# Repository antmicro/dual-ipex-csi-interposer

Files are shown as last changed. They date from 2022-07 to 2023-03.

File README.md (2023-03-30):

# Dual I-PEX CSI Interposer

Copyright (c) 2022-2023 [Antmicro](https://www.antmicro.com)



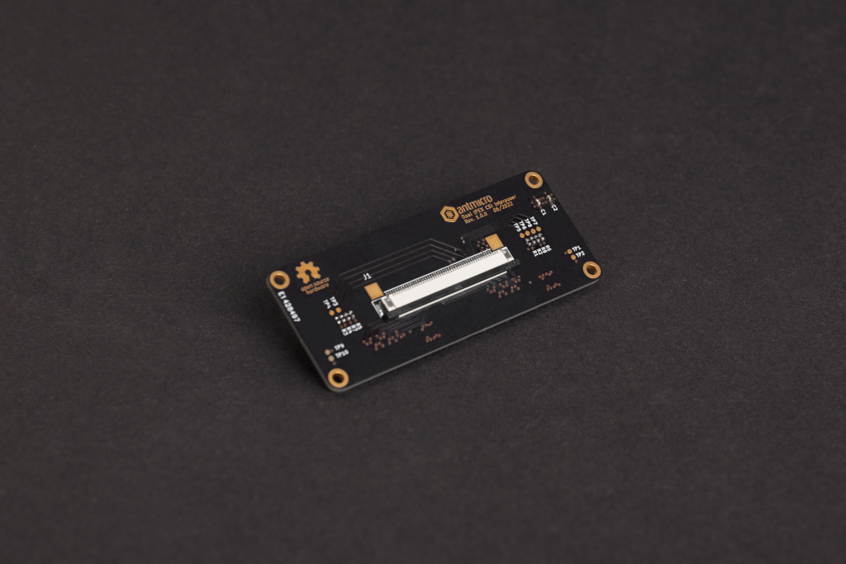
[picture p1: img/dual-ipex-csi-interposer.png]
Dual IPEX CSI Interposer Visualization


## Overview

This repository contains open hardware design files for the Dual I-PEX micro-coaxial CSI Interposer.
The board serves as a 2-to-1 CSI-2 camera cable adapter.

It features two 30-pin I-PEX camera connectors with a 4-lane MIPI CSI-2 interface, I2C and power supply as well as a single upstream connector - 50-pin FFC, compatible with video processing boards created by Antmicro such as:

* [TX2 Deep Learning Platform](https://github.com/antmicro/jetson-tx2-deep-learning-platform) supporting NVIDIA Jetson TX2 
* [AGX CSI Adapter](https://github.com/antmicro/jetson-nano-baseboard) supporting NVIDIA Jetson Xavier AGX and NVIDIA Jetson Orin AGX
* [Jetson Nano Baseboard](https://github.com/antmicro/jetson-nano-baseboard) supporting NVIDIA Jetson Nano, Jetson Xavier NX, Jetson TX2 NX
* [AMD-Xilinx Kria K26 Devboard](https://github.com/antmicro/kria-k26-devboard)
* [Antmicro's Snapdragon 625 baseboard](https://github.com/antmicro/snapdragon-625-baseboard)
* [Antmicro's Snapdragon 845 baseboard](https://github.com/antmicro/snapdragon-845-baseboard)

## Repository structure

The main repository directory contains KiCad PCB project files, a [LICENSE](LICENSE), and a README.
The remaining files are stored in the following directories:

* `lib` - contains the component libraries,
* `doc` - contains the adapter [schematics](doc/dual-ipex-csi-interposer.pdf),
* `img` - contains the board visualization.

## Key features

* 50-pin dual MIPI CSI-2 FFC connector (host side),
* twin 30-wire I-PEX micro coax CSI-2 connectors (camera side) (interface compatible with the [Framos CSI Adapter](https://github.com/antmicro/framos-csi-adapter)),
* 4-lane MIPI CSI-2 per camera.

## License

This project is published under the [Apache-2.0](LICENSE) license.

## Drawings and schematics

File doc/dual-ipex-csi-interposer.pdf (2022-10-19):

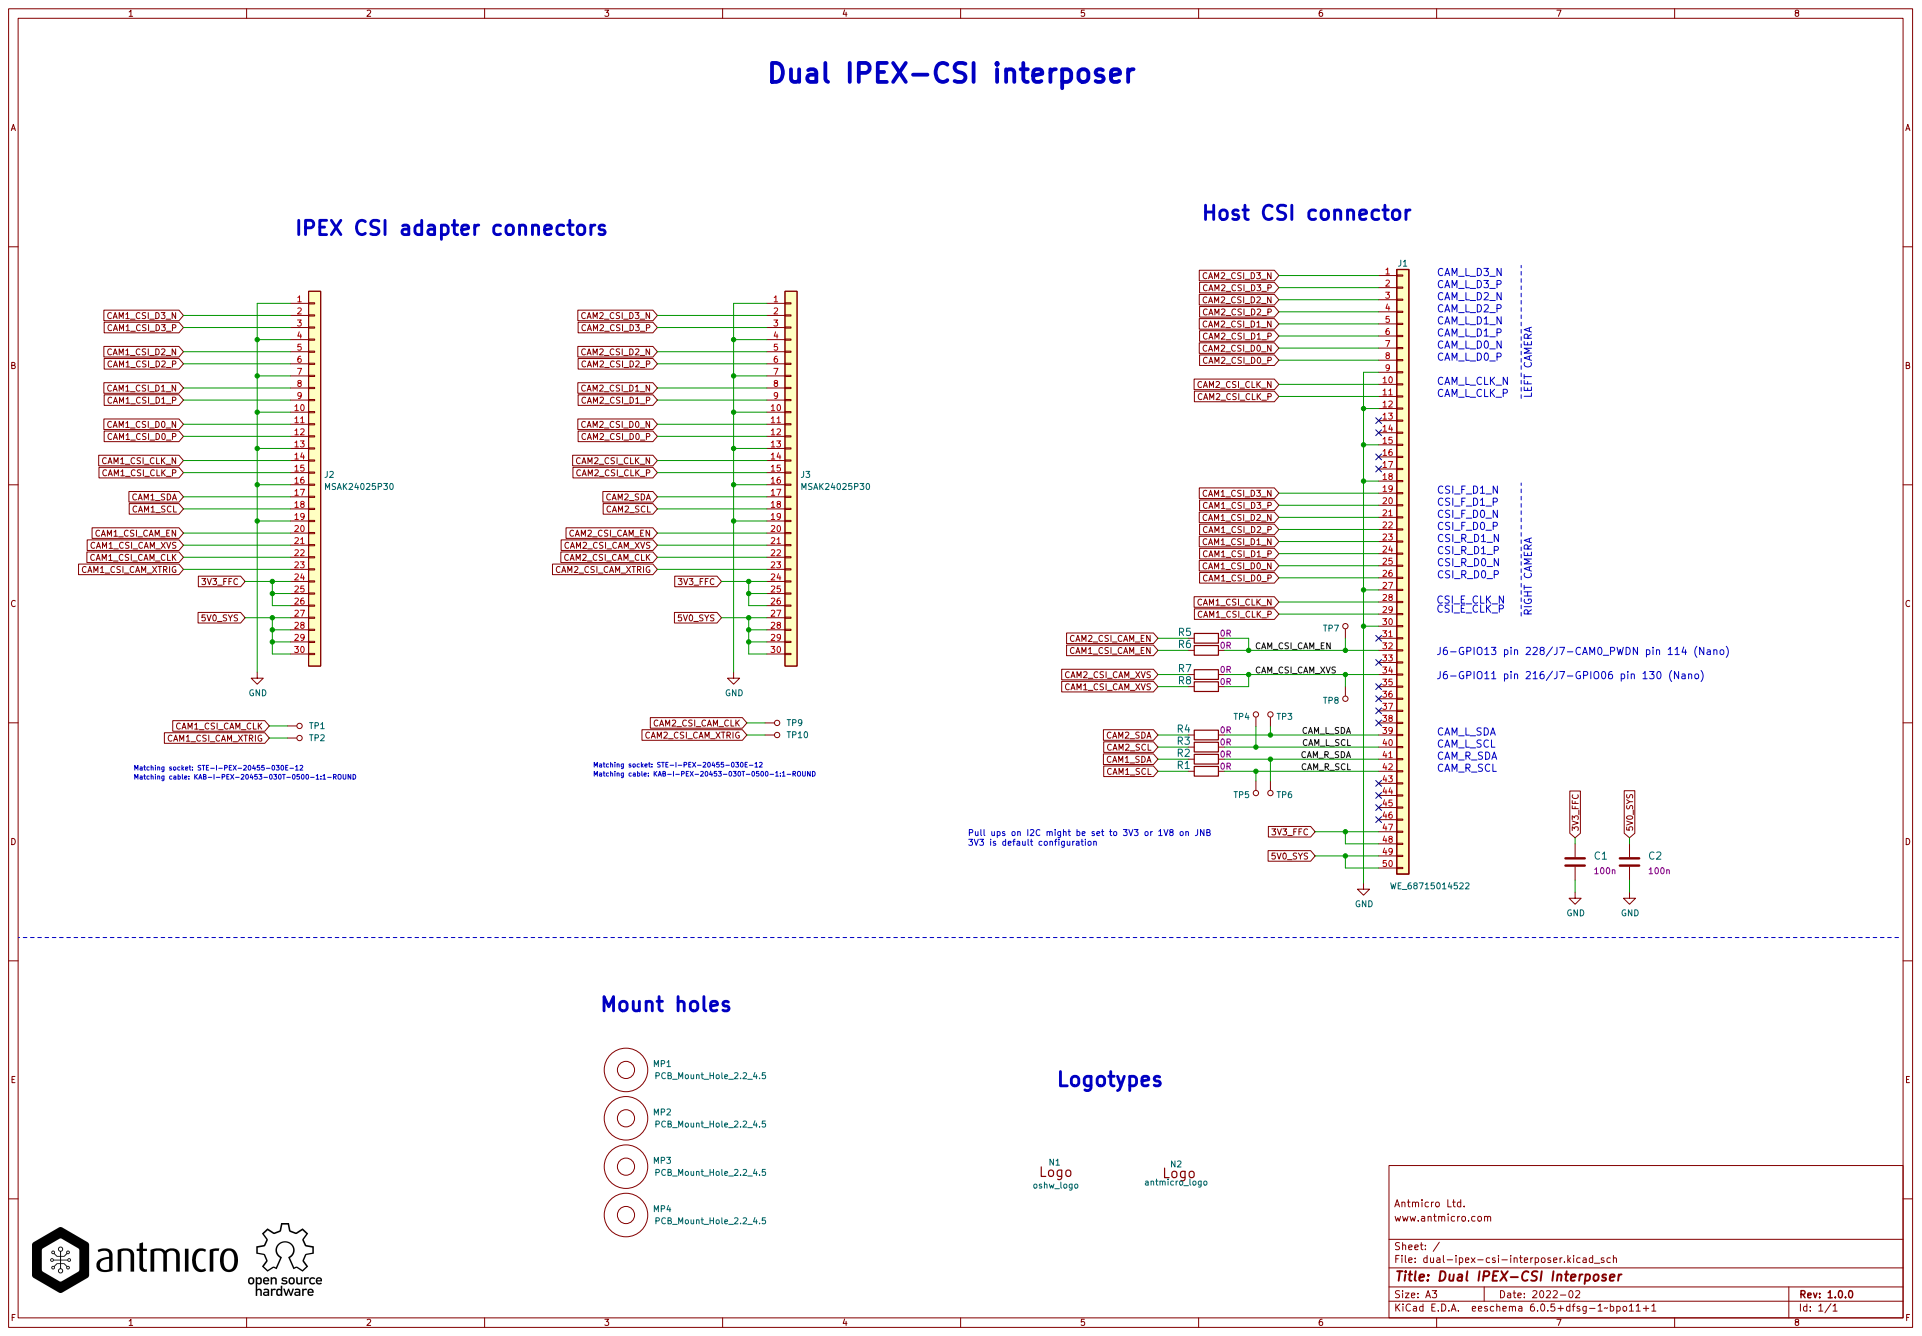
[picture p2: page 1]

IPEX CSI adapter connectors

Pull ups on I2C might be set to 3V3 or 1V8 on JNB
3V3 is default configuration

File: dual-ipex-csi-interposer.kicad_sch Sheet: / www.antmicro.com

Id: 1/1 Title: Dual IPEX-CSI Interposer

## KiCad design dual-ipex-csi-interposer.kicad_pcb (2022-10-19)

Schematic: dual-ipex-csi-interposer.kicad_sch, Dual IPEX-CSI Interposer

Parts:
C1, C2: C_100n_0402; 0402-cap; MPN GRM155R61H104KE14D
J1: WE_68715014522; MPN 68715014522
J2, J3: MSAK24025P30; MPN MSAK24025P30
MP1, MP2, MP3, MP4: PCB_Mount_Hole_2.2_4.5; mounting-hole-2.2mm
N1: oshw_logo; oshw-logo
N2: antmicro_logo; antmicro-logo_scaled_12mm
R1, R2, R3, R4, R5, R6, R7, R8: R_0R_0402; 0402-res; MPN ERJ2GE0R00X
TP1, TP2, TP3, TP4, TP5, TP6, TP7, TP8, TP9, TP10: TP_SMD1MM; Testpoint_smd_1mm

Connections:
3V3_FFC: C1.1, J1.47, J1.48, J2.24, J2.25, J2.26, J3.24, J3.25, J3.26
5V0_SYS: C2.1, J1.49, J1.50, J2.27, J2.28, J2.29, J2.30, J3.27, J3.28, J3.29, J3.30
/CAM_CSI_CAM_EN: J1.32, R5.2, R6.2, TP7.1
/CAM_CSI_CAM_XVS: J1.34, R7.2, R8.2, TP8.1
/CAM_L_SCL: J1.40, R3.2, TP4.1
/CAM_L_SDA: J1.39, R4.2, TP3.1
/CAM_R_SCL: J1.42, R1.2, TP5.1
/CAM_R_SDA: J1.41, R2.2, TP6.1
CAM1_CSI_CAM_CLK: J2.22, TP1.1
CAM1_CSI_CAM_EN: J2.20, R6.1
CAM1_CSI_CAM_XTRIG: J2.23, TP2.1
CAM1_CSI_CAM_XVS: J2.21, R8.1
CAM1_CSI_CLK_N: J1.28, J2.14
CAM1_CSI_CLK_P: J1.29, J2.15
CAM1_CSI_D0_N: J1.25, J2.11
CAM1_CSI_D0_P: J1.26, J2.12
CAM1_CSI_D1_N: J1.23, J2.8
CAM1_CSI_D1_P: J1.24, J2.9
CAM1_CSI_D2_N: J1.21, J2.5
CAM1_CSI_D2_P: J1.22, J2.6
CAM1_CSI_D3_N: J1.19, J2.2
CAM1_CSI_D3_P: J1.20, J2.3
CAM1_SCL: J2.18, R1.1
CAM1_SDA: J2.17, R2.1
CAM2_CSI_CAM_CLK: J3.22, TP9.1
CAM2_CSI_CAM_EN: J3.20, R5.1
CAM2_CSI_CAM_XTRIG: J3.23, TP10.1
CAM2_CSI_CAM_XVS: J3.21, R7.1
CAM2_CSI_CLK_N: J1.10, J3.14
CAM2_CSI_CLK_P: J1.11, J3.15
CAM2_CSI_D0_N: J1.7, J3.11
CAM2_CSI_D0_P: J1.8, J3.12
CAM2_CSI_D1_N: J1.5, J3.8
CAM2_CSI_D1_P: J1.6, J3.9
CAM2_CSI_D2_N: J1.3, J3.5
CAM2_CSI_D2_P: J1.4, J3.6
CAM2_CSI_D3_N: J1.1, J3.2
CAM2_CSI_D3_P: J1.2, J3.3
CAM2_SCL: J3.18, R3.1
CAM2_SDA: J3.17, R4.1
GND: C1.2, C2.2, J1.9, J1.12, J1.15, J1.18, J1.27, J1.30, J2.1, J2.4, J2.7, J2.10, J2.13, J2.16, J2.19, J3.1, J3.4, J3.7, J3.10, J3.13, J3.16, J3.19

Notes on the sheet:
CAM_L_D1_P
CAM_L_SDA
CSI_E_CLK_N
CSI_E_CLK_P
CAM_L_D2_P
CAM_R_SCL
Matching cable: KAB-I-PEX-20453-030T-0500-1:1-ROUND
Pull ups on I2C might be set to 3V3 or 1V8 on JNB 3V3 is default configuration
CAM_L_D0_N
CSI_F_D0_P
Text
CSI_R_D0_P
CAM_L_D0_P
CAM_L_D1_N
Dual IPEX-CSI interposer
CSI_R_D1_P
CAM_L_CLK_P
CSI_R_D1_N
J6-GPIO13 pin 228/J7-CAM0_PWDN pin 114 (Nano)
Mount holes
Matching socket: STE-I-PEX-20455-030E-12
CAM_L_D3_P
CAM_R_SDA
LEFT CAMERA
CAM_L_CLK_N
CSI_F_D1_P
J6-GPIO11 pin 216/J7-GPIO06 pin 130 (Nano)
IPEX CSI adapter connectors
RIGHT CAMERA
CSI_R_D0_N
Logotypes
CSI_F_D0_N
CAM_L_D3_N
Host CSI connector
CAM_L_D2_N
CSI_F_D1_N
CAM_L_SCL

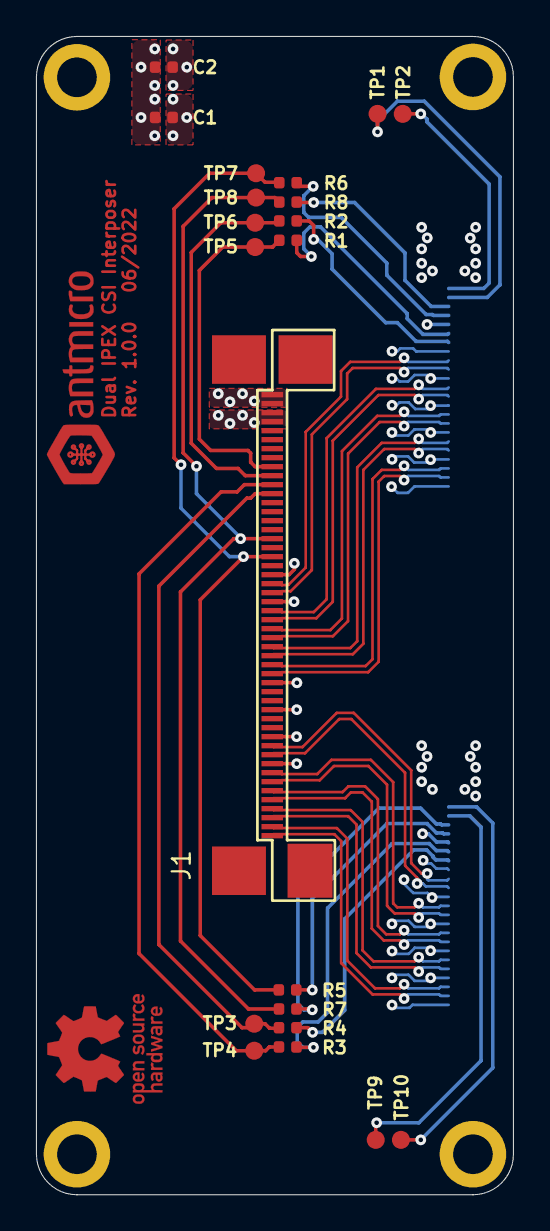
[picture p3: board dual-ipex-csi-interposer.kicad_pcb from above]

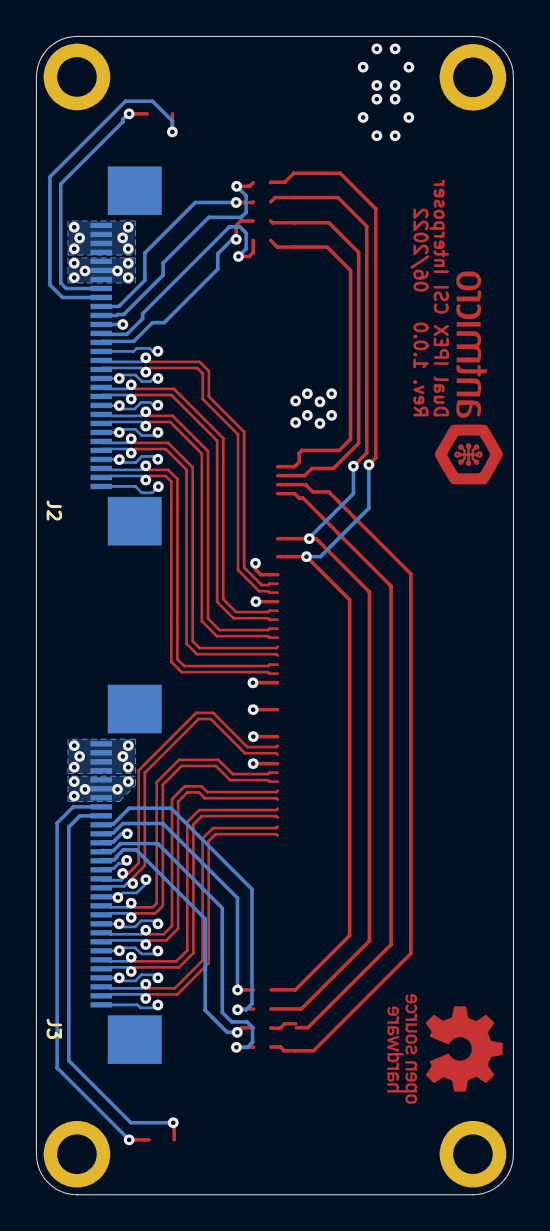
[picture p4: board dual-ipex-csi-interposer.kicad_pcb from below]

Board: 4 copper layers, 26.5 x 64.3 mm, 29 parts (2 on the bottom side), 41 nets.

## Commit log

2022-07-28 Initial commit. Add single IPEX
    Fix library issue
    [antmicro-dual-ipex-csi-interposer.kicad_pcb, antmicro-dual-ipex-csi-interposer.kicad_sch, antmicro-dual-ipex-csi-interposer.sch]
2022-07-28 Add second connector and assigned signals
    Remove Kicad5 CI
    [antmicro-dual-ipex-csi-interposer.kicad_pcb, antmicro-dual-ipex-csi-interposer.kicad_sch, antmicro-dual-ipex-csi-interposer.sch]
2022-07-28 Complete schematic. Proceed PCB layout
    [antmicro-dual-ipex-csi-interposer.kicad_pcb, antmicro-dual-ipex-csi-interposer.kicad_sch]
2022-07-28 Route low speed, optimize polygons, match lane length
    [antmicro-dual-ipex-csi-interposer.kicad_pcb, antmicro-dual-ipex-csi-interposer.kicad_sch]
2022-07-28 Add decoupling, move all TP to the top
    Cosmetic changes
    Capital letter fix
    [antmicro-dual-ipex-csi-interposer.kicad_pcb, antmicro-dual-ipex-csi-interposer.kicad_sch]
2022-07-28 Generate loclib. Cleanup
    Add boards image. Add image link to README
    [antmicro-dual-ipex-csi-interposer.kicad_pcb, antmicro-dual-ipex-csi-interposer.kicad_sch]
2022-10-19 Edit README
    [dual-ipex-csi-interposer.kicad_pcb, dual-ipex-csi-interposer.kicad_sch]
2022-10-19 Update schematic PDF
